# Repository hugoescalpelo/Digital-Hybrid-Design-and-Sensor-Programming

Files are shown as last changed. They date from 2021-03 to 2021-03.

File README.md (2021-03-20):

# Digital Hybrid Design and Sensor Programming
 Circuits, sensors programming and 3D printed Parts

**Digital Hybrid**

*Digital Hybrid* is a project from [Anni Garza Lau](http://www.annigarzalau.com/ "Anni Garza Lau") as part of [ACT](http://https://www.artecienciaytecnologias.mx/ "ACT") (Art, Cience and Technology Grant from Secretaria de Cultura, Mexico). This project is a collaboration between Anni Garza Lau, [Vladimir Sánchez Garrido](https://www.linkedin.com/in/vladimirsaga/ "Vladimir Sanches Garrido"), [Eddie Castañeda](https://2-2-0.online/ "Eddie Castañeda"), [Mariel Paredes](https://www.instagram.com/marielfashionfit/ "Mariel Paredes") y [Hugo Escalpelo](http://hugoescalpelo.com "Hugo Escalpelo").

*Digital Hybrid* is an art and technology project composed of a suit full of sensors and an artificial intelligence with its own personality. The sensors report the vital signs of their user and information about the environment in which they are. This information influences the behavior and vital signs of artificial intelligence, which is programmed to survive and feel pleasure and pain. Under Reinforcement Learning rules, artificial intelligence interacts with social networks and the contextual information at its disposal, sending sound messages, text and stimuli to the user to transform their behavior in their favor, however, it is expected that this behavior will become a win-win interaction.

**Role division**

Below is the division of roles.

- Anni Garza Lau. Creativa, user of the Digital Hybrid suit, Project Director.
- Mariel Paredes. Fashion designer.
- Eddie Castañeda. Computer vision manager
- Yunuen SaGa. Artificial intelligence developer, contextualizer developer and data visualization
- Hugo Escalpelo. Circuit designer, designer of 3D printed parts.

**Software Needed**

*3D printed Parts*

- SolidWorks 2020

*Laser Cut Parts*

- InkScape

*Circuits*

- Autidesk Eagle

*nVidia Jetson*

- L4T 4.3
- Ubuntu 18.04 LTS
- LibRealsense-utils
- LibRealsense-dev
- JetPack Installer 3.2.1
- NodeJS 14 LTS
- NodeRed 1.2.7
- NPM
- node-red-node-serialport Nodes
- node-red-node-twitter Nodes
- node-red-dashboard Nodes
- node-red-contrib-fitbit Nodes

**General System Description**

This diagram shows working stages at electronic level. This diagram does not includes IA systems.

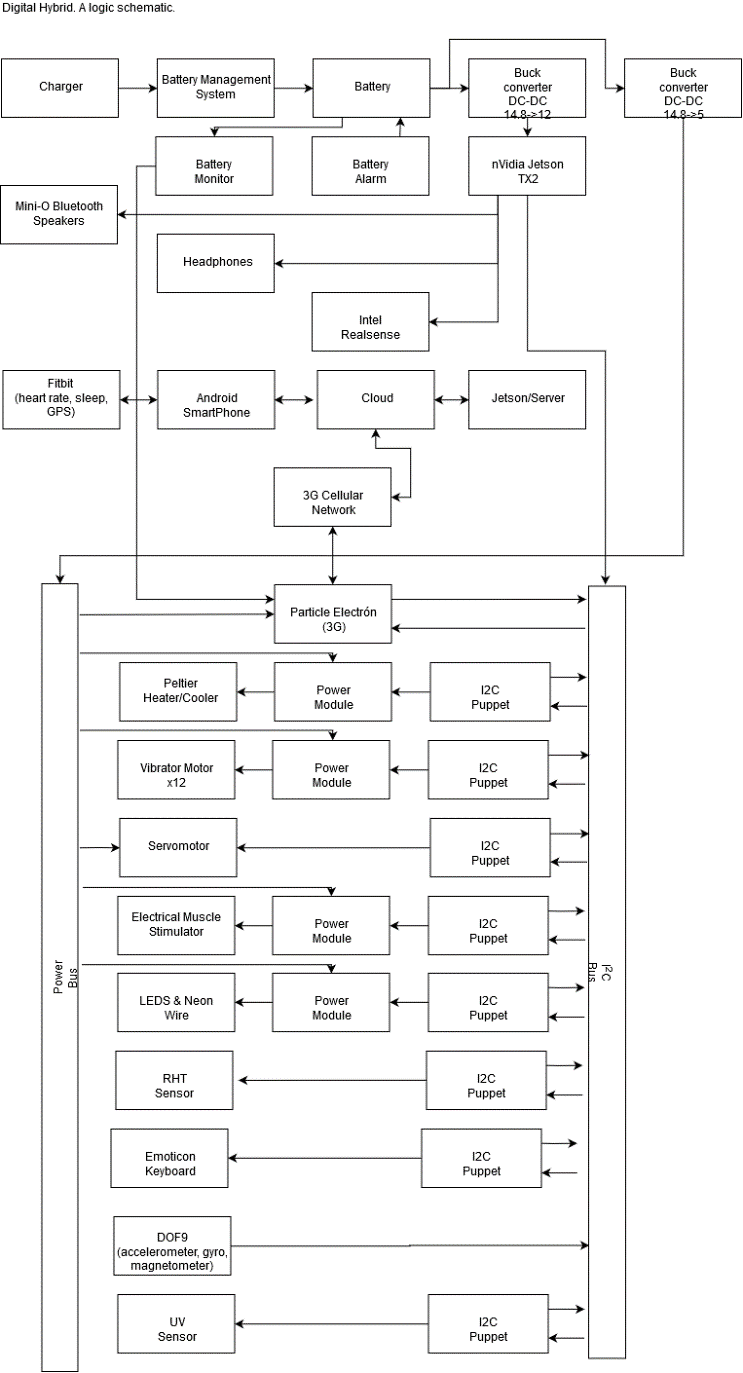
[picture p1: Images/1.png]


**How to do it**

Video tutorials soon to be added.

**Instructions**

This is a big and complex Project. See Instructions Folder for more details on the many stages of reproducing this project.

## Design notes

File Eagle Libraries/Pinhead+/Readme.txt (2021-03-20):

This library is an extension of the default pinhead library. 
It contains all the devices and packages in that library, plus the surface mount versions of 0.1" 1x3-1x20 and 2x3-2x20 pin header, and 2x2 0.1" pin header.

Written by Spence Konde (2014) http://drazzy.com/e - distribute freely.

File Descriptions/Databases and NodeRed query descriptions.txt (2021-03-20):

\sql
\connect root@localhost
\connect hugov7zv_act1@207.174.215.153
dosdepastor
CREATE DATABASE digitalhybrid;
show databases;
use hugov7zv_DigitalHybrid;
CREATE TABLE sensors (id INT(6) UNSIGNED AUTO_INCREMENT PRIMARY KEY, fecha TIMESTAMP DEFAULT CURRENT_TIMESTAMP, uv INT(1) UNSIGNED NOT NULL, temp FLOAT(4,2) NOT NULL, hum INT(1) UNSIGNED NOT NULL, buttons INT(1) UNSIGNED NOT NULL, motion INT(1) UNSIGNED NOT NULL, batt INT(1) UNSIGNED NOT NULL, lat DOUBLE(9,6) NOT NULL, lon DOUBLE(9,6) NOT NULL);
show tables;

//Insert
msg.topic="INSERT INTO sensors (uv,temp,hum,buttons,motion,batt,lat,lon) VALUES ('"+msg.payload.uv+"','"+msg.payload.temp+"','"+msg.payload.hum+"','"+msg.payload.buttons+"','"+msg.payload.motion+"','"+msg.payload.batt+"','"+msg.payload.lat+"','"+msg.payload.lon+"')";
Variable names in JSON are the same as columns in table database

//Social database
CREATE TABLE social (id INT (6) UNSIGNED AUTO_INCREMENT PRIMARY KEY, fecha TIMESTAMP DEFAULT CURRENT_TIMESTAMP, id2 INT(1) UNSIGNED NOT NULL, text CHAR(248) CHARACTER SET utf8, imgPath CHAR(248) CHARACTER SET utf8);
msg.topic="INSERT INTO social (id2, text, imgPath) VALUES ('"+msg.payload.id2+"','"+msg.payload.text+"','"+msg.payload.imgPath+"')";

//See table details
describe sensors;

//Drop table;22
DROP TABLE sensors;

//Permitir acceso desde windows a mysql 8
CREATE USER 'root'@'%' IDENTIFIED BY '123';
GRANT ALL PRIVILEGES ON *.* TO 'root'@'%';

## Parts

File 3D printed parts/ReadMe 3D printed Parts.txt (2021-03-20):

Note!

There is a missing file in GrabCad Folder due to Large Size. The file is P2371-top_asm. You need to download it sepparately from the following link and put it in the GrabCad folder in order the assembly to work!

https://grabcad.com/library/jetson-tx2-1#!

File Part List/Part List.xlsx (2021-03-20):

Componentes electrónicos ACT |  |  |  |  | USD | 26 | IVA | 1.16 | Amortizaje % | 1.15
 | No. | Cantidad | Concepto | Detalle | USD Pieza | USD Lote | MXN Pieza | MXN Lote | MXN IVA | Precio amortizado | Enlace
 | 1 | 2 | nVidia Jetson tx2 developer kit | Micro computadora para redes neuronales | 599 | 1198 |  | 31148 | 36131.68 | 41551.432 | https://www.amazon.com/NVIDIA-Jetson-TX2-Development-Kit/dp/B06XPFH939
 | 2 | 2 | Particle Electron Evaluation Kit | Micro controlador con conexion 3G | 69 | 138 |  | 3588 | 4162.08 | 4786.392 | https://store.particle.io/collections/electron
 | 3 | 2 | Bateria de Litio | 11V 5000 mAh |  |  | 3578 | 7156 | 8300.96 | 9546.104 | https://www.amazon.com.mx/Venom-5000mAh-Hardcase-Battery-Universal/dp/B003T6S2I4
 | 4 | 1 | 9-DOF sensor | Sensor de orientación absoluta | 34.95 | 34.95 |  | 908.7 | 1054.092 | 1212.2058 | https://www.adafruit.com/product/2472
 | 5 | 1 | DHT11 sensor | Sensor de temperatura y humedad relativa | 5 | 5 |  | 130 | 150.8 | 173.42 | https://www.adafruit.com/product/386
 | 6 | 1 | SI1145 Sensor | Sensor de luz visible, infrarroja y UV | 9.95 | 9.95 |  | 258.7 | 300.092 | 345.1058 | https://www.adafruit.com/product/1777
 | 7 | 1 | BITalino Board Kit | Sensor cardiaco ECG y muscular EMG | 209.95 | 209.95 |  | 5458.7 | 6332.092 | 7281.9058 | https://www.sparkfun.com/products/14022
 | 8 | 2 | Intel RealSense Depth Camera | Camara de profundidad | 179 | 358 |  | 9308 | 10797.28 | 12416.872 | https://click.intel.com/intelr-realsensetm-depth-camera-d435.html
 | 9 | 1 | Bone conducting headphones | Audifonos de conduccion osea | 59.95 | 59.95 |  | 1558.7 | 1808.092 | 2079.3058 | https://aftershokz.com/collections/wired/products/sportz-titanium-with-mic
 | 10 | 1 | Mini-O Ultra flat BT speaker | Bocinas ultra delgadas | 80 | 80 |  | 2080 | 2412.8 | 2774.72 | https://www.amazon.com/Mini-Portable-Bluetooth-Speaker-Pair/dp/B07959QTFN
 | 11 | 1 | Electronic Pulse Massager | Masajeador de pulsos electrónicos | 18.99 | 18.99 |  | 493.74 | 572.7384 | 658.64916 | https://www.amazon.com/AUVON-Portable-Stimulator-Electronic-Compatible/dp/B075JMMQ8R
 | 12 | 2 | Peltier Thermo-Electric Cooler | Elemento termo eléctrico activo | 14.95 | 29.9 |  | 777.4 | 901.784 | 1037.0516 | https://www.adafruit.com/product/1331
 | 13 | 12 | Vibrating Mini Motor Disc | Mini motor vibrador | 1.95 | 23.4 |  | 608.4 | 705.744 | 811.6056 | https://www.adafruit.com/product/1201
 | 14 | 1 | Galvanic skin Response Tracker | Pulsera de monitoreo galvanico de piel | 90 | 90 |  | 2340 | 2714.4 | 3121.56 | https://www.amazon.com/Jawbone-Heart-Activity-Sleep-Tracker/dp/B00N9E6DUK?s=hpc
 | 15 | 1 | Cargador Lipo | Cargador para bateria general | 37.9 | 37.9 |  | 985.4 | 1143.064 | 1314.5236 | https://www.amazon.com/EV-PEAK-50Watts-Battery-Balance-Charger/dp/B01NCRDNGJ?s=toys-and-games
 | 16 | 1 | Corsair RGB PWM fan | Ventilador RGB controlado por pwm | 39.99 | 39.99 |  | 1039.74 | 1206.0984 | 1387.01316 | https://www.amazon.com/Corsair-LL140-Single-Cooling-CO-9050073-WW/dp/B075VHBC4S?s=pc
 | 17 | 2 | Neopixel 15x5050 | Anillo de 16 leds RGB | 9.95 | 19.9 |  | 517.4 | 600.184 | 690.2116 | https://www.adafruit.com/product/1463
 | 18 | 3 | Neopixel 12x5050 | Anillo de 12 leds RGB | 7.5 | 22.5 |  | 585 | 678.6 | 780.39 | https://www.adafruit.com/product/1643
 | 19 | 6 | Sensor AT42QT1012 | Sensor capacitivo de conmutacion | 5.95 | 35.7 |  | 928.2 | 1076.712 | 1238.2188 | https://www.adafruit.com/product/1375
 | 20 | 1 | Rollo de cable calibre 12 | Para conexiones |  |  | 450 | 450 | 522 | 600.3
 | 21 | 2 | Cinta de aislar liquida | Para aislar conexiones |  |  | 34.9 | 69.8 | 80.968 | 93.1132 | https://www.officedepot.com.mx/officedepot/en/Categor%C3%ADa/Todas/Oficina/B%C3%A1sicos-de-Papeler%C3%ADa/Cintas-Adhesivas/CINTA-DE-AISLAR-LIQUIDA/p/76495
 | 22 | 2 | Rollo de soldadura | 450 gramos |  |  | 495 | 990 | 1148.4 | 1320.66 | http://www.steren.com.mx/rollo-de-450-gramos-de-soldadura-con-aleacion-estano-plomo-63-37.html
 | 23 | 3 | Placa fenolica de 10X15 | Placa de cobre para circuitos |  |  | 29 | 87 | 100.92 | 116.058 | http://www.steren.com.mx/placa-fenolica-una-cara-de-10-x-15-cm.html
 | 24 | 100 | Resistencias | Valores varios |  |  | 1 | 100 | 116 | 133.4 | http://www.steren.com.mx/resistencia-de-carbon-de-1-2-watt-al-5-de-tolerancia-de-1-5-kohms.html
 | 25 | 20 | Capacitor | Valores varios |  |  | 3 | 60 | 69.6 | 80.04 | http://www.steren.com.mx/capacitor-electrolitico-radial-de-22-uf-micro-faradios-a-50-volts.html
 | 26 | 1 | Conectores | Set de conectores varios |  |  | 400 | 400 | 464 | 533.6
 | 27 | 5 | Micro Servomotor | Motor con control de posición | 11.95 | 59.75 |  | 1553.5 | 1802.06 | 2072.369 | https://www.adafruit.com/product/2307
 |  |  |  |  |  |  |  | Total | 85353.2408 | 98156.22692
Componentes de fabricación ACT |  |  |  |  | USD | 26 | IVA | 1.16 | Amortizaje % | 1.15
 | No. | Cantidad | Concepto | Detalle | USD Pieza | USD Lote | MXN Pieza | MXN Lote | MXN IVA | Precio amortizado | Enlace
 | 28 | 2 | eSun PLA filament | Filamento para impresión 3D | 26 | 52 |  | 1352 | 1568.32 | 1803.568 | https://www.amazon.com/eSUN-1-75mm-Printer-Filament-2-2lbs/dp/B01EKEMB7Q?s=hpc
 | 29 | 50 | Set de tornillos | Para ensamblado |  |  | 5 | 250 | 290 | 333.5
 | 30 | 6 | Poliester | 1,60x1 m |  |  | 80 | 480 | 556.8 | 640.32
 | 31 | 2 | Plastipiel | 1,60x1 m |  |  | 95 | 190 | 220.4 | 253.46
 | 32 | 2 | Velcro | Rollo |  |  | 180 | 360 | 417.6 | 480.24
 | 33 | 2 | Cremallera | Metros |  |  | 60 | 120 | 139.2 | 160.08
 | 34 | 2 | Hilo cañamo | Rollo |  |  | 30 | 60 | 69.6 | 80.04
 | 35 | 5 | Agujas | Para maquina de coser |  |  | 50 | 250 | 290 | 333.5
 |  |  |  |  |  |  |  | Total | 3551.92 | 4084.708
Servicios ACT |  |  |  |  | USD | 26 | IVA | 1.16 | Amortizaje % | 1.15
 | No. | Cantidad | Concepto | Detalle | USD Pieza | USD Lote | MXN Pieza | MXN Lote | MXN IVA | Precio amortizado | Enlace
 | 36 | 2 | Host + Dominio | Año |  |  | 1860 | 3720 | 4315.2 | 4962.48 | https://mx.godaddy.com/hosting/web-hosting
 | 37 | 15 | Impresion 3D | Hora |  |  | 600 | 9000 | 10440 | 12006 | http://www.materiam.com/en_US/request-for-quote
 | 38 | 10 | Maquinado CNC | Hora |  |  | 720 | 7200 | 8352 | 9604.8 | http://www.materiam.com/en_US/request-for-quote
 | 39 | 10 | Maquilado Textil | Hora |  |  | 300 | 3000 | 3480 | 4002
 | 40 | 1 | Plan de datos Celular | 1 mes, 2 gb |  |  | 500 | 500 | 580 | 667
 | 41 | 0 | Envio | Para todas las importaciones |  |  | 7000 | 0 | 0 | 0
 | 42 | 0 | Aduana | Para todas las importaciones |  |  | 16000 | 0 | 0 | 0
 |  |  |  |  |  |  |  | Total | 27167.2 | 31242.28

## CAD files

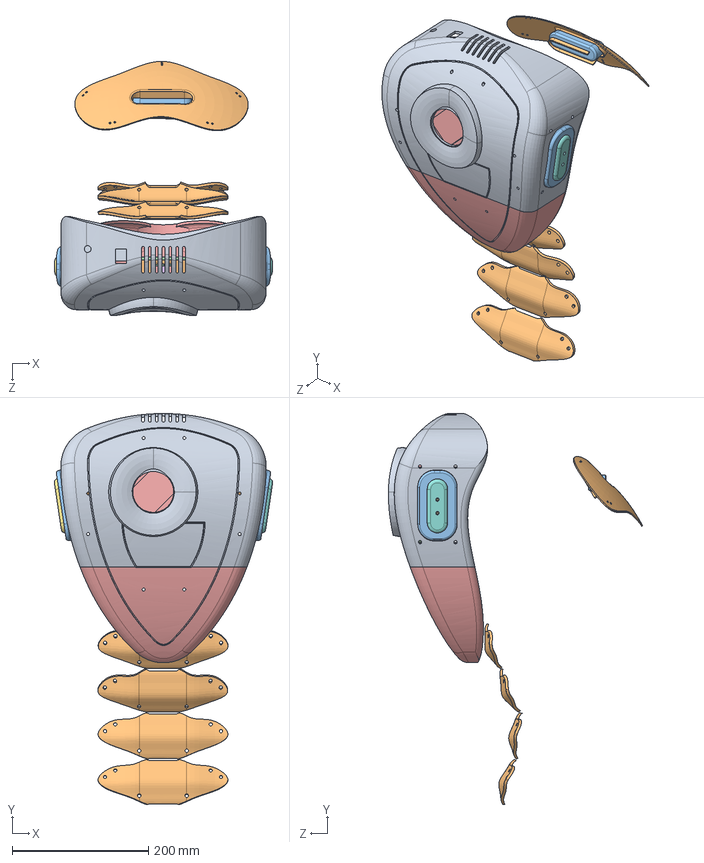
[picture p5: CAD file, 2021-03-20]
3D printed parts/Ensamble Mochila Render.SLDASM
320.2 x 573.3 x 372.8 mm
backpack 2g bottom
Vertebra x 4
Base
Board
Separador x 4
Pieza soporte bocina izquierda
Seguro bocina izquierda
jetson holder --
jetson holder ++
jetson holder -+
jetson holder +-
backpack 2g
Pieza soporte bocina derecha
Seguro bocina der
Union left
Sensores
Pecho
Realsense
Broche
Galss

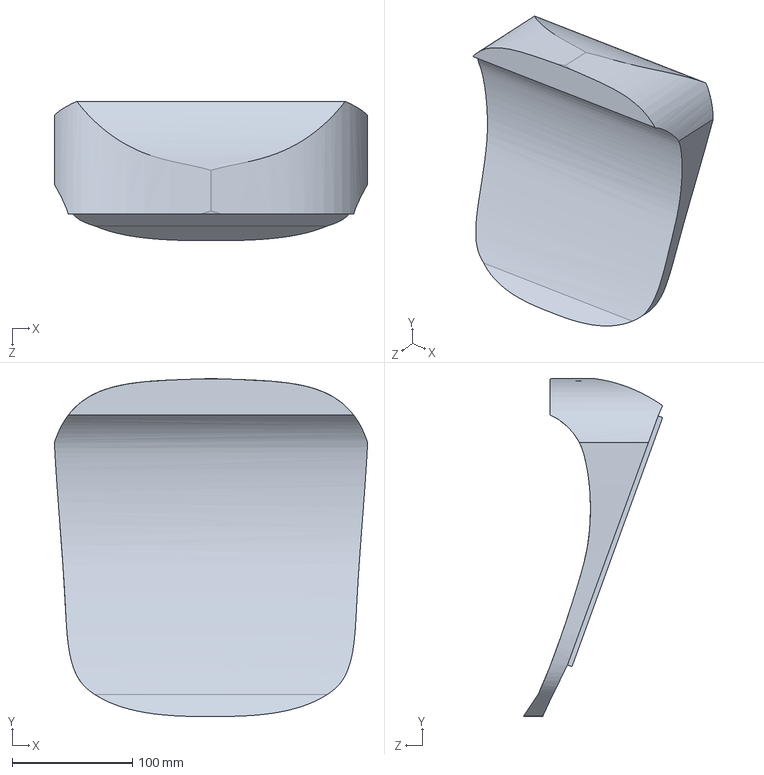
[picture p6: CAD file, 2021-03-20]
3D printed parts/Assem1.SLDASM
260.0 x 280.5 x 115.6 mm

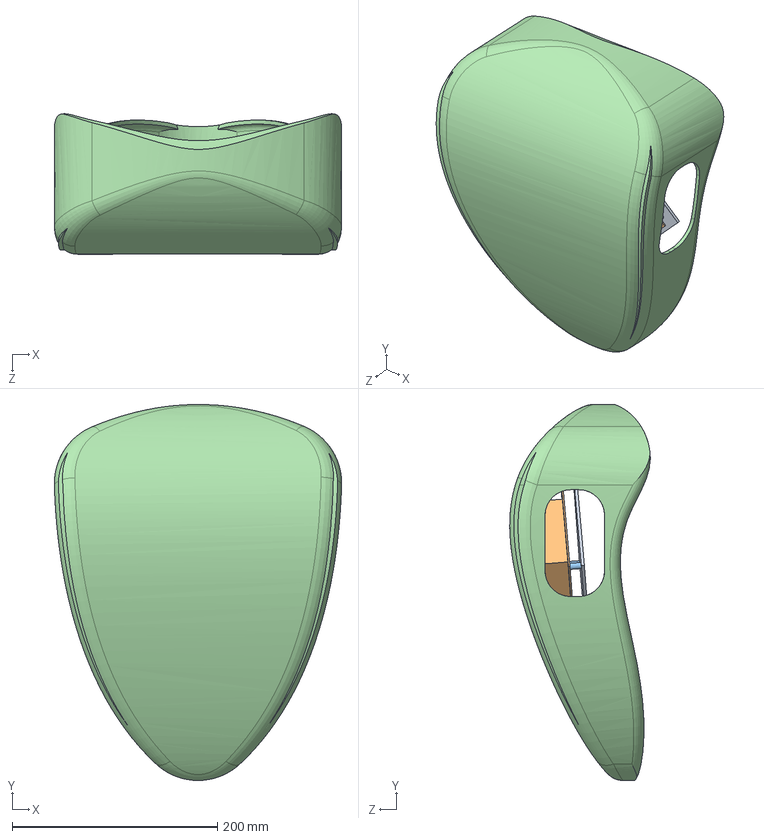
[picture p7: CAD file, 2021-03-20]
3D printed parts/Backpack/MOchila Wrap.SLDASM
279.8 x 366.1 x 136.9 mm
Base
Board
Separador x 4
backpack 2d

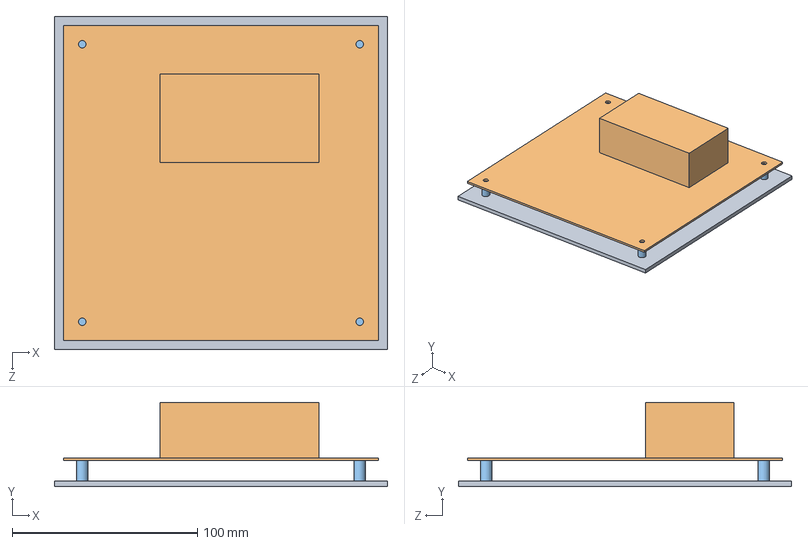
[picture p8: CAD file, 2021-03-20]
3D printed parts/Jetson H/Jetson H.SLDASM
180.0 x 45.5 x 180.0 mm
Base
Board
Separador x 4

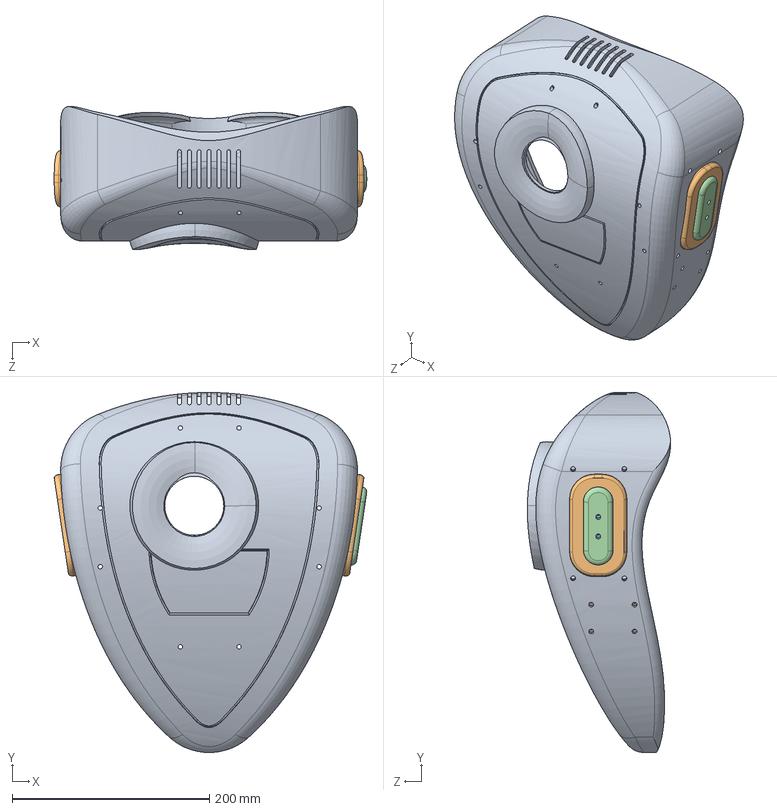
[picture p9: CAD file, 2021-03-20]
3D printed parts/Moldes/left holder.SLDASM
317.3 x 365.4 x 145.5 mm
backpack 2g botttom
Pieza soporte bocina izquierda
Seguro bocina izquierda
Union left

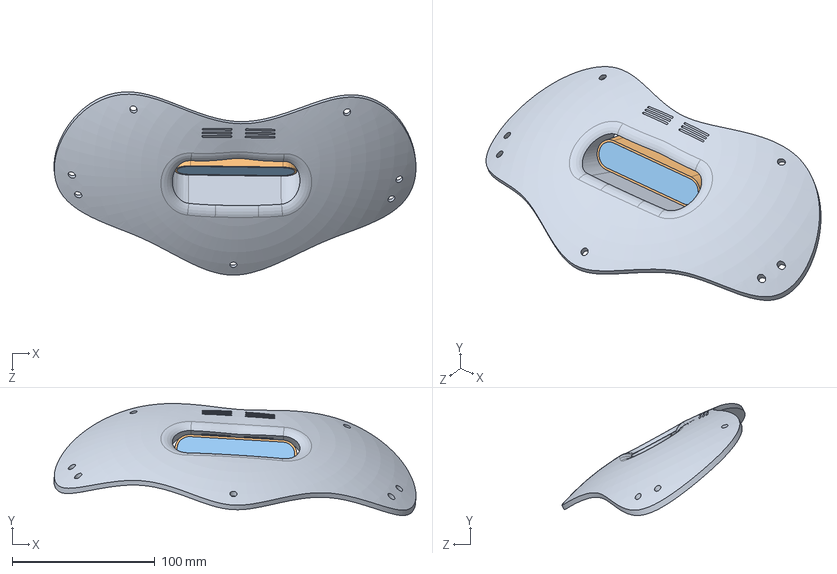
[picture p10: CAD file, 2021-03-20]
3D printed parts/Realsense/Frente Ensamble.SLDASM
253.7 x 78.5 x 128.5 mm
Pecho
Realsense
Galss

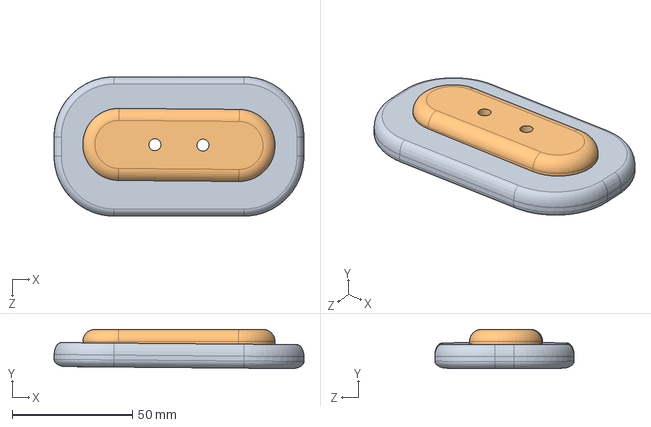
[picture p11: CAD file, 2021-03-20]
3D printed parts/Moldes/left lock.SLDASM
104.0 x 16.3 x 58.0 mm
Seguro bocina izquierda

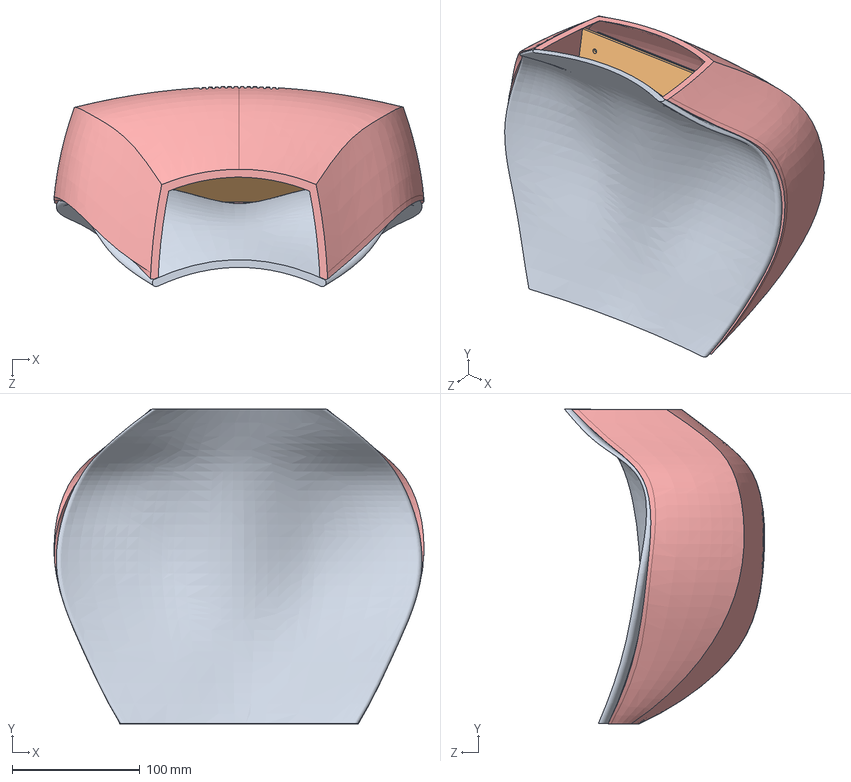
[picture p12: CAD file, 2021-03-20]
3D printed parts/Backpack/Mochila.SLDASM
289.3 x 246.1 x 156.6 mm
Molde
Base
Board
Separador x 4
Cubierta

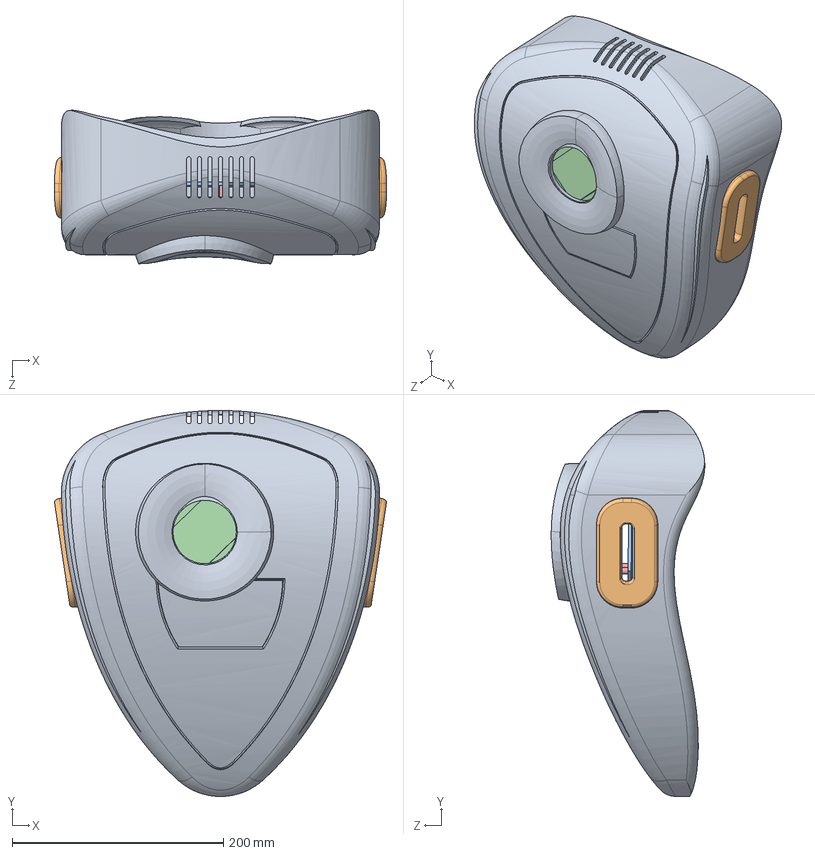
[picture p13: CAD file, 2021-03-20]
3D printed parts/Backpack/Mochila b.SLDASM
314.3 x 365.4 x 145.4 mm
backpack 2e
Base
Board
Separador x 4

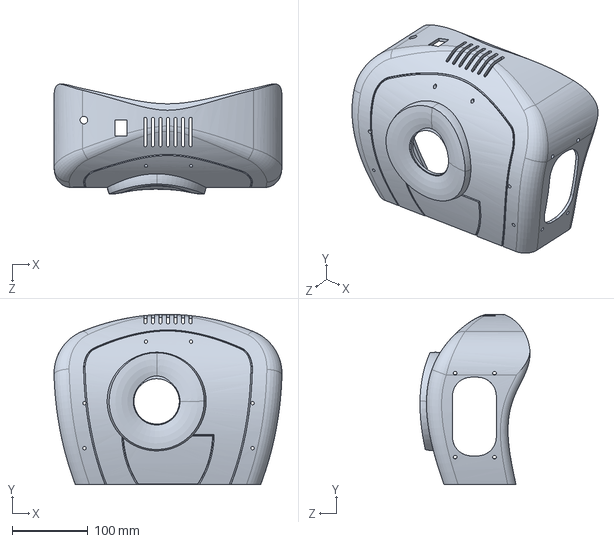
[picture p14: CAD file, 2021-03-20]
3D printed parts/Backpack/backpack 2g bottom.SLDPRT
301.3 x 225.0 x 145.5 mm

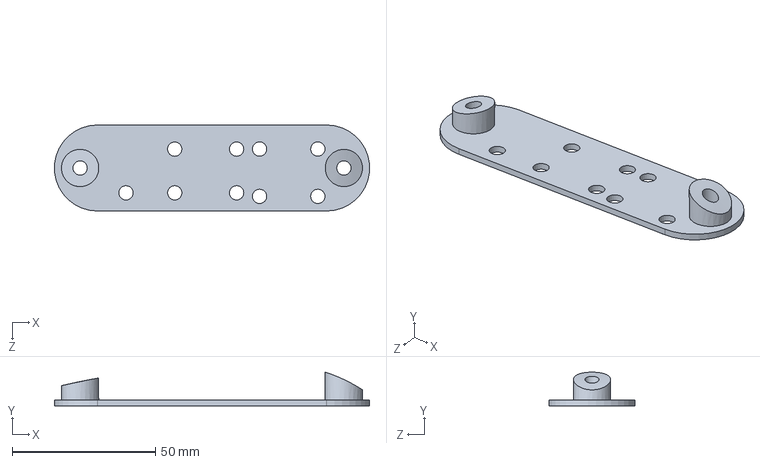
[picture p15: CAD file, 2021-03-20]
3D printed parts/Bases circuitos/Sensores.SLDPRT
109.9 x 11.8 x 30.0 mm

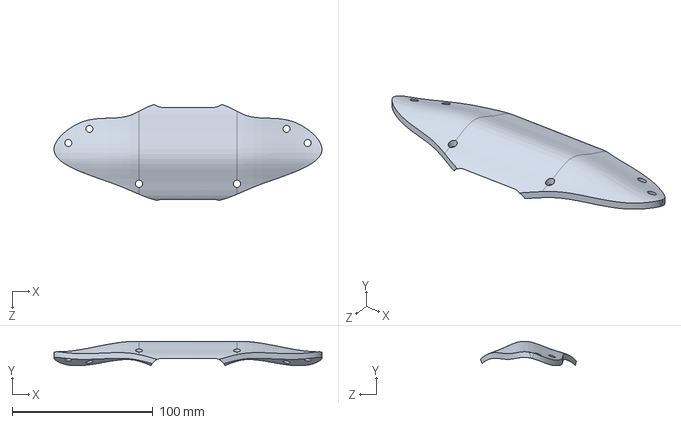
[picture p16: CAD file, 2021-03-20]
3D printed parts/Columna/Vertebra.SLDPRT
190.3 x 17.4 x 68.1 mm

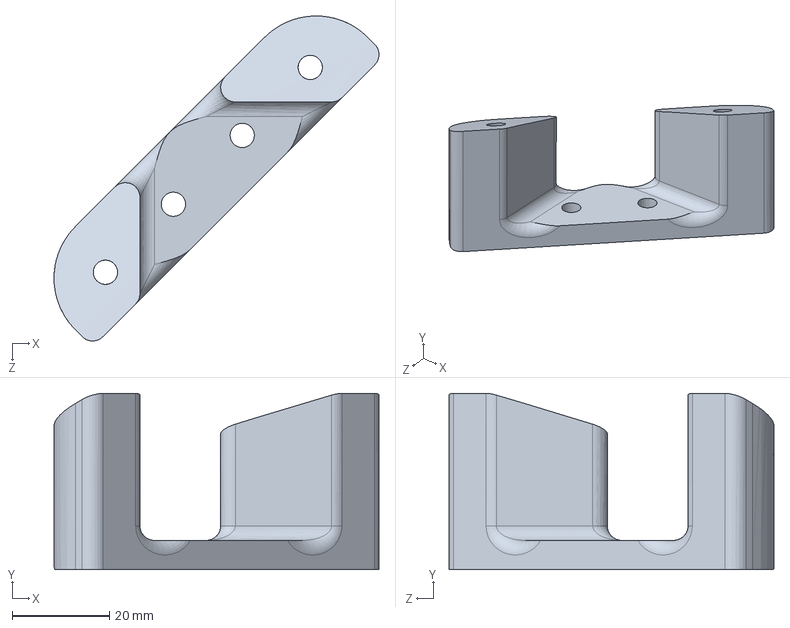
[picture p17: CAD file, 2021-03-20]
3D printed parts/Jetson H/jetson holder --.SLDPRT
66.8 x 36.2 x 66.8 mm

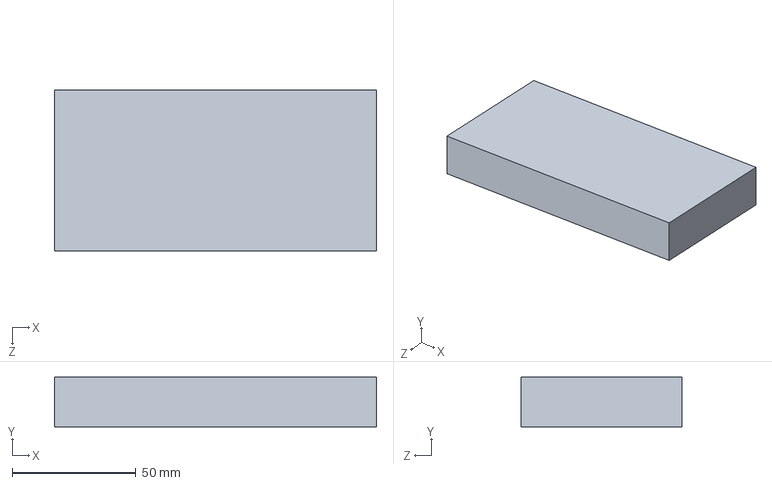
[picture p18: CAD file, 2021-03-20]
3D printed parts/Mini-o/Holder speaker.SLDPRT
130.0 x 20.0 x 65.0 mm

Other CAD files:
3D printed parts/Ensamble Mochila.SLDASM
3D printed parts/Brazo/Brazo.SLDPRT
3D printed parts/Moldes/Seguro bocina izquierda.SLDPRT
3D printed parts/Pecho/Part2.SLDPRT
3D printed parts/Backpack/BackPack Completo.STL
3D printed parts/Backpack/Backpack 3D printing 4mm.STL
3D printed parts/Backpack/Backpack 3D printing.STL
3D printed parts/Backpack/Backpack Completo + Base.STL
3D printed parts/Backpack/Cubierta.SLDPRT
3D printed parts/Backpack/Molde.SLDPRT
3D printed parts/Backpack/Part1.STL
3D printed parts/Backpack/Union right.SLDPRT
3D printed parts/Backpack/backpack 2.SLDPRT
3D printed parts/Backpack/backpack 2b.SLDPRT
3D printed parts/Backpack/backpack 2c.SLDPRT
3D printed parts/Backpack/backpack 2d.SLDPRT
3D printed parts/Backpack/backpack 2e.SLDDRW
3D printed parts/Backpack/backpack 2e.SLDPRT
3D printed parts/Backpack/backpack 2e.STL
3D printed parts/Backpack/backpack 2f.SLDPRT
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

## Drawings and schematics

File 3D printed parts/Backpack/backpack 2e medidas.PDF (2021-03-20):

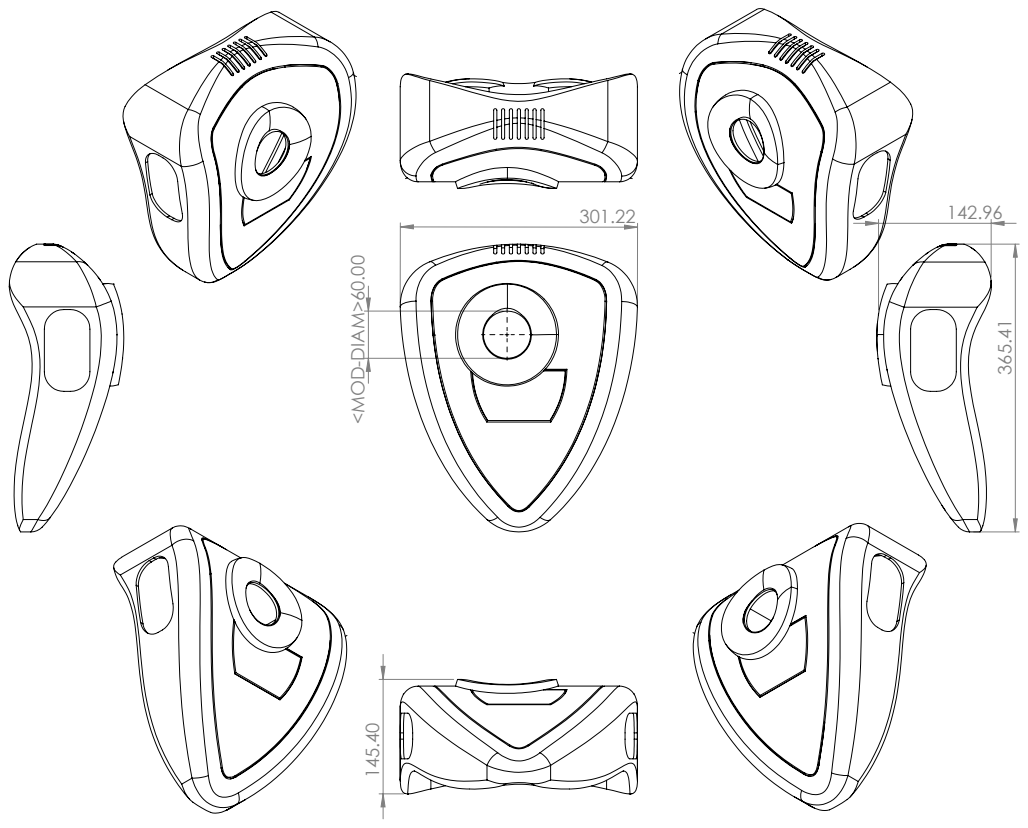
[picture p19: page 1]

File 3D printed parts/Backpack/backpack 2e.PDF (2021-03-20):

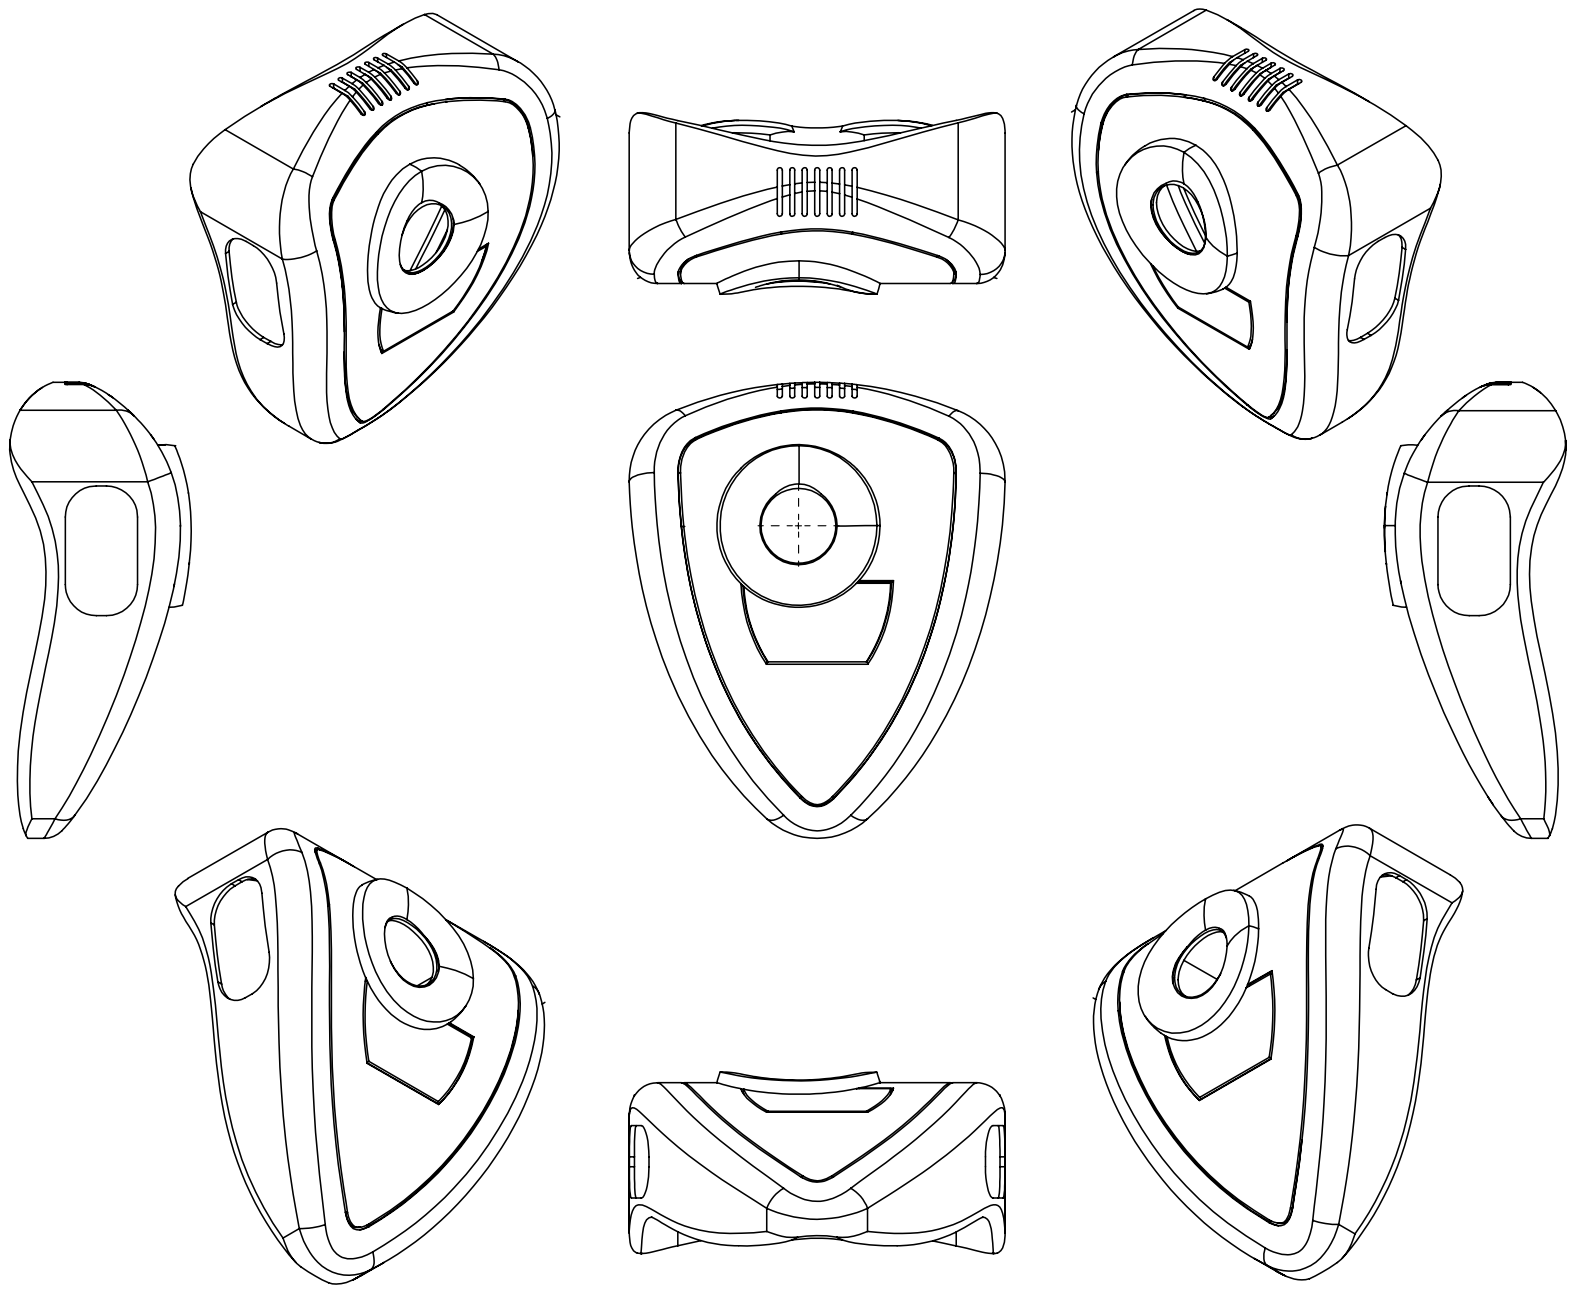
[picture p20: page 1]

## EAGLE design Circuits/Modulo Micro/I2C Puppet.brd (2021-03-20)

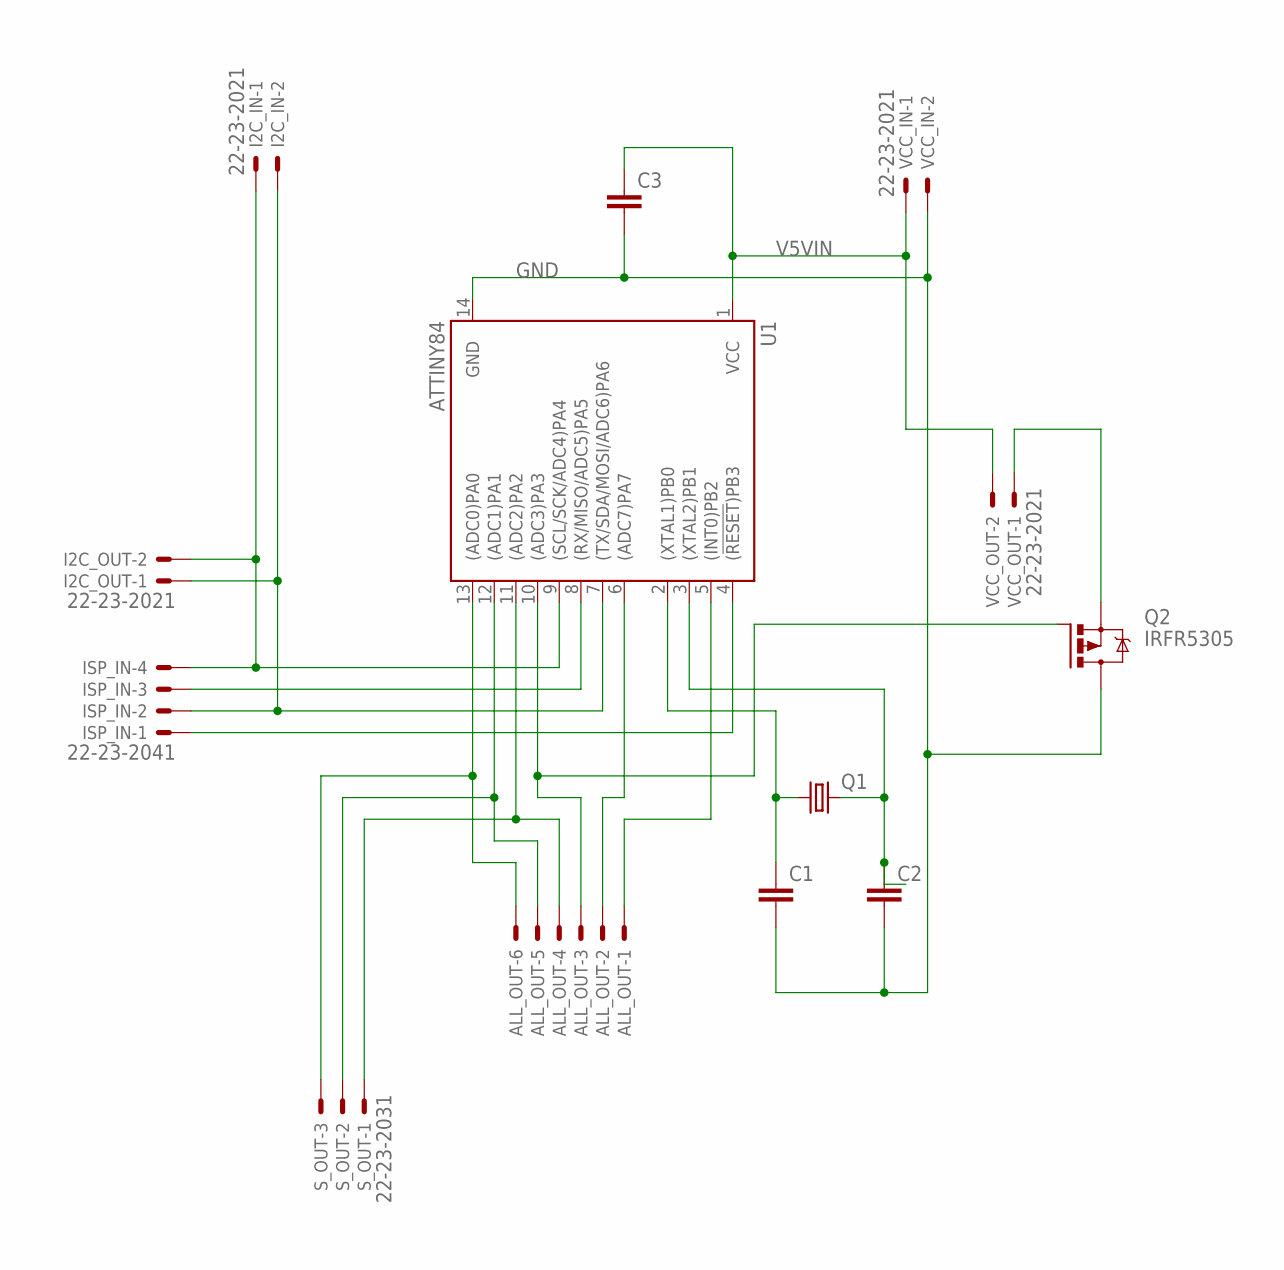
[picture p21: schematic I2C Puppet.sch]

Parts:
ALL_OUT: 22-23-2061
C1, C2, C3: C-EUC1210; C1210
I2C_IN, I2C_OUT: 22-23-2021
ISP_IN: 22-23-2041
Q1: CRYSTALHC49UP; HC49UP
Q2: IRFR5305; D-PAK_TO252AA
S_OUT: 22-23-2031
U1: ATTINY84; SO14
VCC_IN: 22-23-2021
VCC_OUT: 22-23-2021

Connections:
GND: C1.2, C2.2, C3.2, Q2.4 (D), U1.14 (GND), VCC_IN.2
unnamed: ALL_OUT.4, S_OUT.1, U1.11 ((ADC2)PA2)
unnamed: I2C_IN.1, I2C_OUT.2, ISP_IN.4, U1.9 ((SCL/SCK/ADC4)PA4)
unnamed: I2C_IN.2, I2C_OUT.1, ISP_IN.2, U1.7 ((TX/SDA/MOSI/ADC6)PA6)
unnamed: C1.1, Q1.1, U1.2 ((XTAL1)PB0)
unnamed: C2.1, Q1.2, U1.3 ((XTAL2)PB1)
unnamed: ISP_IN.1, U1.4 ((!RESET!)PB3)
unnamed: Q2.3 (S), VCC_OUT.1
unnamed: ISP_IN.3, U1.8 ((RX/MISO/ADC5)PA5)
unnamed: ALL_OUT.6, S_OUT.3, U1.13 ((ADC0)PA0)
unnamed: ALL_OUT.5, S_OUT.2, U1.12 ((ADC1)PA1)
unnamed: ALL_OUT.3, Q2.1 (G), U1.10 ((ADC3)PA3)
unnamed: ALL_OUT.2, U1.6 ((ADC7)PA7)
unnamed: ALL_OUT.1, U1.5 ((INT0)PB2)
V5VIN: C3.1, U1.1 (VCC), VCC_IN.1, VCC_OUT.2

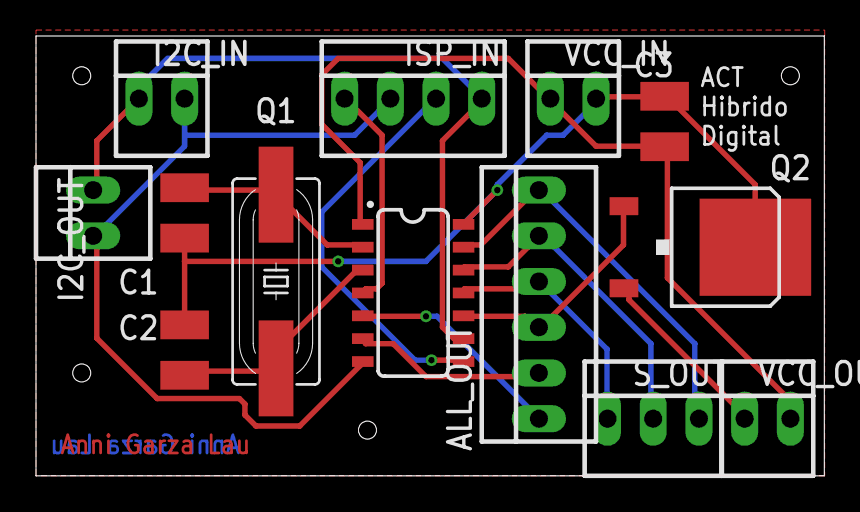
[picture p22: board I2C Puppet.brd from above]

Board: 2 copper layers, 43.8 x 24.4 mm, 13 parts (0 on the bottom side), 15 nets.

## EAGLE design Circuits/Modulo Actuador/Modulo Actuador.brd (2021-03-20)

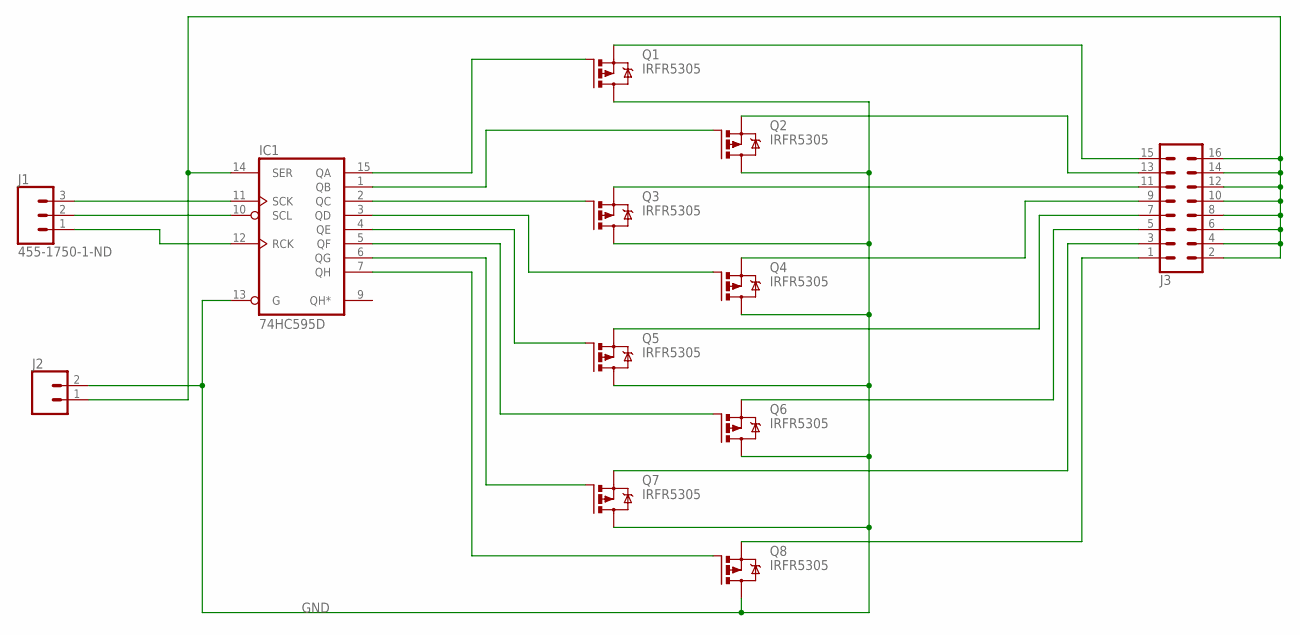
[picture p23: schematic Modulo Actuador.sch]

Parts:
IC1: 74HC595D; SO16
J1: 455-1750-1-ND; 1X03
J2: CONN_02; 1X02
J3: CONN_08X2_HEADER; 2X8
Q1, Q2, Q3, Q4, Q5, Q6, Q7, Q8: IRFR5305; D-PAK_TO252AA

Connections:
GND: IC1.8 (GND), IC1.13 (G), J2.2, Q1.4 (D), Q2.4 (D), Q3.4 (D), Q4.4 (D), Q5.4 (D), Q6.4 (D), Q7.4 (D), Q8.4 (D)
unnamed: IC1.14 (SER), J2.1, J3.2, J3.4, J3.6, J3.8, J3.10, J3.12, J3.14, J3.16
unnamed: IC1.12 (RCK), J1.1
unnamed: IC1.10 (SCL), J1.2
unnamed: IC1.11 (SCK), J1.3
unnamed: IC1.15 (QA), Q1.1 (G)
unnamed: IC1.1 (QB), Q2.1 (G)
unnamed: IC1.2 (QC), Q3.1 (G)
unnamed: IC1.3 (QD), Q4.1 (G)
unnamed: IC1.4 (QE), Q5.1 (G)
unnamed: IC1.5 (QF), Q6.1 (G)
unnamed: IC1.6 (QG), Q7.1 (G)
unnamed: IC1.7 (QH), Q8.1 (G)
unnamed: J3.15, Q1.3 (S)
unnamed: J3.13, Q2.3 (S)
unnamed: J3.11, Q3.3 (S)
unnamed: J3.1, Q8.3 (S)
unnamed: J3.3, Q7.3 (S)
unnamed: J3.5, Q6.3 (S)
unnamed: J3.7, Q5.3 (S)
unnamed: J3.9, Q4.3 (S)
VCC: IC1.16 (VCC)

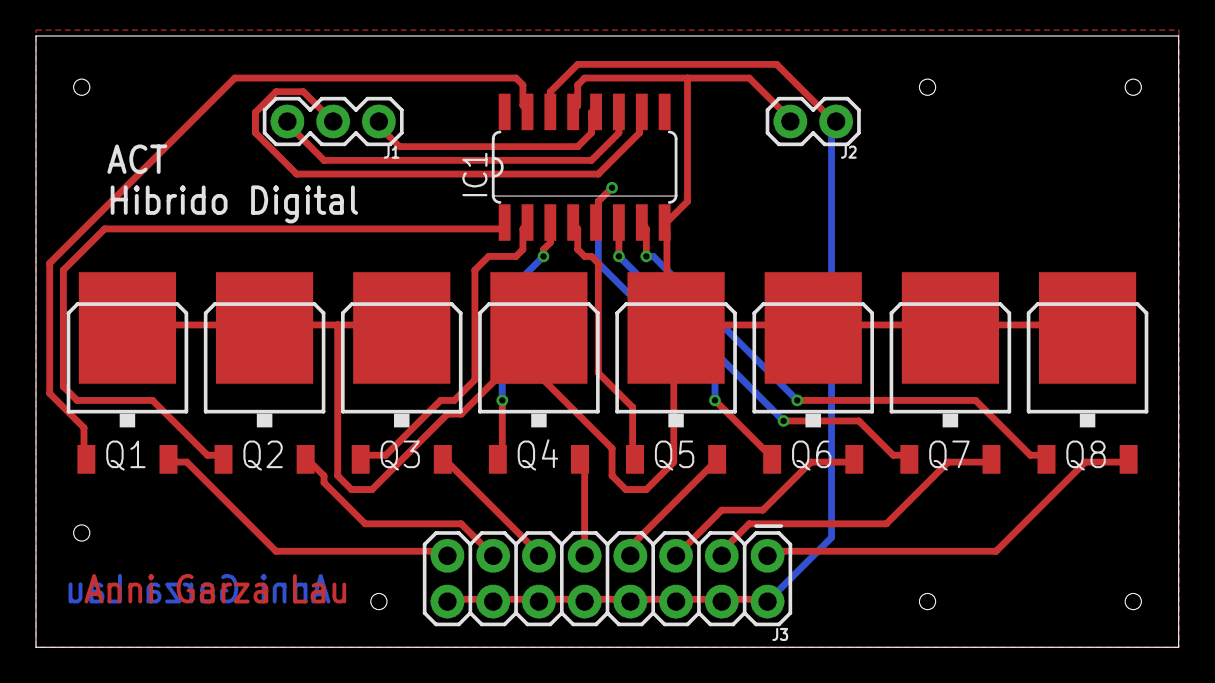
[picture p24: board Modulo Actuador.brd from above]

Board: 2 copper layers, 63.5 x 34.0 mm, 12 parts (0 on the bottom side), 21 nets.

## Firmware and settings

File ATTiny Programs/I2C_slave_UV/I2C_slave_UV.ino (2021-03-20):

//I2C Slave receiver: Digital Hybrid


#include <Wire.h>

int data = 0;

void setup() {
  Wire.begin(8);                // join i2c bus with address #8
  Wire.onReceive(receiveEvent); // register event
  Serial.begin(9600);           // start serial for output
}

void loop() {
  delay(60000);//Read every minute
  if (data != 0) {
    Wire.write (data);
    delay (1000);
    data = 0;
  }
}

// function that executes whenever data is received from master
// this function is registered as an event, see setup()
void receiveEvent(int howMany) {
  while (1 < Wire.available()) { // loop through all but the last
    char c = Wire.read(); // receive byte as a character
    Serial.print(c);         // print the character
  }
  int x = Wire.read();    // receive byte as an integer
  Serial.println(x);         // print the integer

  if (x == 3) {
    data = analogRead (3);
  }
  
})

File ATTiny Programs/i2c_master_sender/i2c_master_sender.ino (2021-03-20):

#include <Wire.h>

void setup() {
  Wire.begin();
  Serial.begin(9600);
}

byte x = 0;

void loop() {
  Wire.beginTransmission(0x05);
  Wire.write("x is ");
  Wire.write(x);
  Wire.endTransmission();

  Wire.requestFrom(8, 6);    // request 6 bytes from slave device #8

  while (Wire.available()) { // slave may send less than requested
    char c = Wire.read(); // receive a byte as character
    Serial.print(c);         // print the character
  }

  x++;
  delay(500);
}

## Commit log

2021-03-20 Solidos agregados
    Se agregaron todos los solidos
    [Assem1.SLDASM, BackPack Completo.STL, Backpack 3D printing 4mm.STL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]
2021-03-20 Note due to large size model
    Large size model note added, nVidia Jetson model too big. Software needed list added to readme.md
2021-03-20 Circuits Added
    Circuits Added
    [I2C Puppet.brd, I2C Puppet.sch, Modulo Actuador.brd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]
2021-03-20 Laser cut Parts Added
    Laser cut Parts Added
    [Disco.DXF]
2021-03-20 NodeRed Flows added
    NodeRed Flows added
2021-03-20 Part List Added
    Part List Added
    [Part List.xlsx]

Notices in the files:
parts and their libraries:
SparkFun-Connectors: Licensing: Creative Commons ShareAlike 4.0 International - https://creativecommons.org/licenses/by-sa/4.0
